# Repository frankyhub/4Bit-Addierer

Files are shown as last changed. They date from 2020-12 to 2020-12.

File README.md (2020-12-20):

# 4Bit-Addierer
Projekt Gymnasium Tegernsee

## [Link zur Dokumentation PDF](https://github.com/frankyhub/4Bit-Addierer/blob/main/doc/4-Bit-Addierer-Dokumentation.pdf)

## Frontplatte


## PCB


## Schaltplan Volladdierer



## Schaltplan vier Volladdierer


## 4Bit-Addierer im Gehäuse




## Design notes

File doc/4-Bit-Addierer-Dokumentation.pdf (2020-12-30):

### 4-Bit-Addierer

### Dokumentation

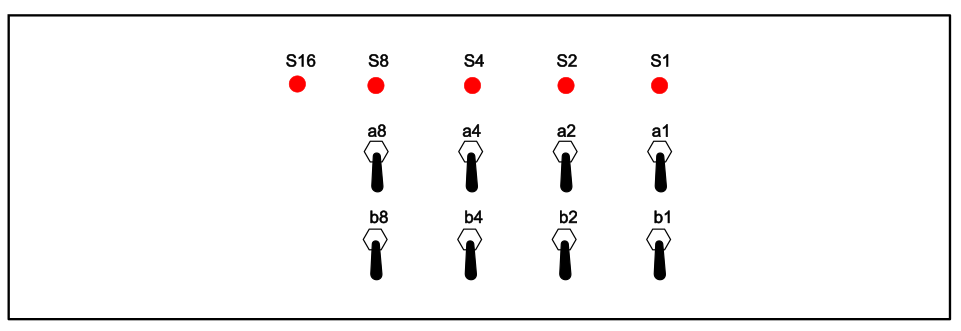
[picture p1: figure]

4-Bit-Addierer

Erstellt: | KHF | Version: | V1.0 | Seite 2 von 6

D:\gittemp\4Bit-Addierer\4-Bit-Addierer-Dokumentation.docx

Beschreibung

Der 4-Bit-Addierer addiert die Bits a1-a8 mit b1-b8 und zeigt die Summe im dualen Zahlensystem mit den LEDs S1-S16 an. Die Beschriftung der Schalter und LEDs resultiert aus der Wertigkeit der Schalter und der LEDs.

Schalter | Wertigkeit binär | Wertigkeit dezimal
a1 | 2 0 | 1
a2 | 2 1 | 2
a4 | 2 2 | 4
a8 | 2 3 | 8
Schalter | Wertigkeit binär | Wertigkeit dezimal
b1 | 0 2 | 1
b2 | 2 1 | 2
b4 | 2 2 | 4
b8 | 3 2 | 8
LED Summe | Wertigkeit binär | Wertigkeit dezimal
S1 | 2 0 | 1
S2 | 2 1 | 2
S4 | 2 2 | 4
S8 | 2 3 | 8
S16 | 4 2 | 16

Schalterstellung unten = 0, Schalterstellung oben = 1

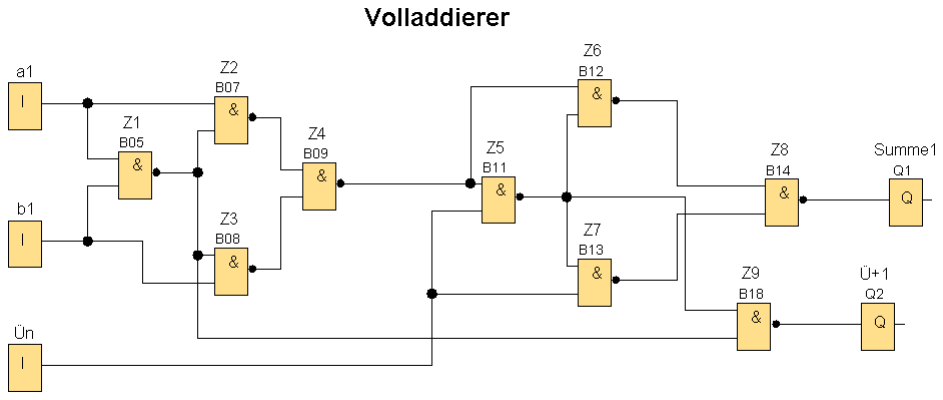
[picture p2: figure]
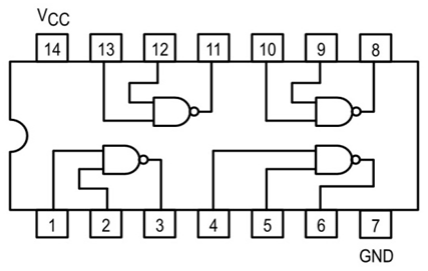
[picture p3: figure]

Erstellt: | KHF | Version: | V1.0 | Seite 3 von 6

Der 4-Bitt-Addierer besteht aus vier Volladdierer:

Ün | a | b | Summe | Ün+1
0 | 0 | 0 | 0 | 0
0 | 0 | 1 | 1 | 0
0 | 1 | 0 | 1 | 0
0 | 1 | 1 | 0 | 1
1 | 0 | 0 | 1 | 0
1 | 0 | 1 | 0 | 1
1 | 1 | 0 | 0 | 1
1 | 1 | 1 | 1 | 1
Funktionstabelle eines Volladdierers

Der 4-Bit-Addierer wurde mit zehn TTL (Transistor-Transistor-Logik) ICs SN74LS00N aufgebaut:

Datasheet SN74LS00N - 4 NAND-Gatter

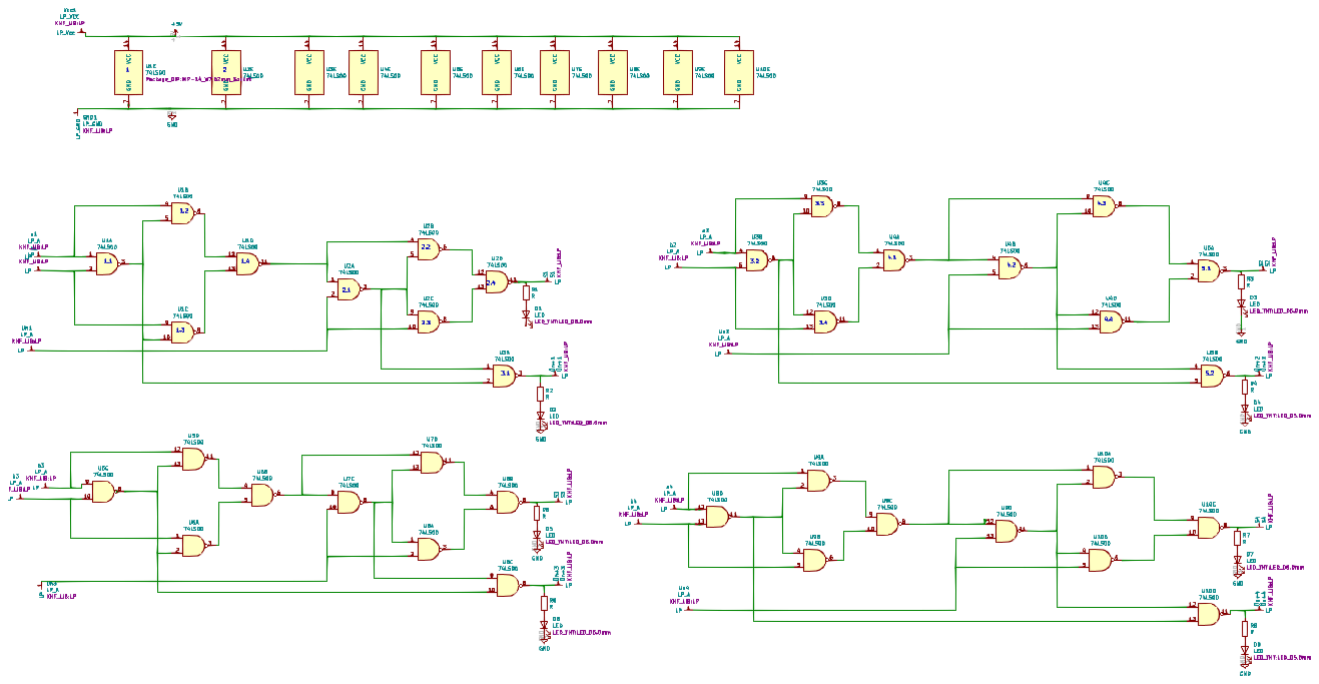
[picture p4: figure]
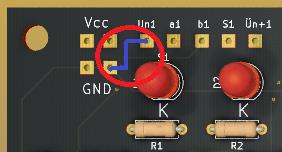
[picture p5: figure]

Erstellt: | KHF | Version: | V1.0 | Seite 4 von 6
Eingang 1 | Eingang 2 | Ausgang
0 | 0 | 1
0 | 1 | 1
0 | 0 | 1
1 | 1 | 0
Funktionstabelle NAND SN74LS00N

Damit die Bits a1-a8 mit den Bits b1-b8 addiert werden können, benötigt man vier Volladdierer.

Schaltplan des 4-Bit-Addierers

Bestehend aus vier Volladdierer

Hinweis: TTL-Bausteine haben die Eigenschaft, einen offenen Eingang als logisch 1 zu erkennen. Deshalb muss der Übertrag Un1 des ersten Addierers mit logisch 0 beschalten werden. Dies erfolgte auf der Platine mit einer Drahtbrücke.

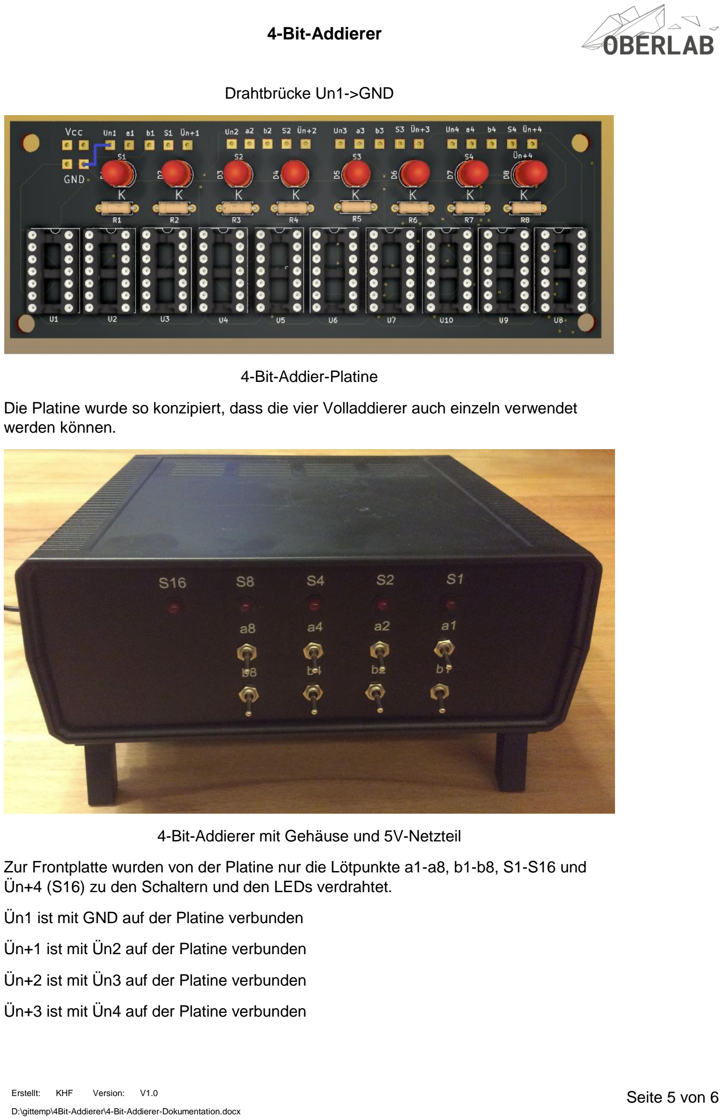
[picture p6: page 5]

Erstellt: | KHF | Version: | V1.0 | Seite 5 von 6

Drahtbrücke Un1->GND

4-Bit-Addier-Platine

Die Platine wurde so konzipiert, dass die vier Volladdierer auch einzeln verwendet werden können.

4-Bit-Addierer mit Gehäuse und 5V-Netzteil

Zur Frontplatte wurden von der Platine nur die Lötpunkte a1-a8, b1-b8, S1-S16 und Ün+4 (S16) zu den Schaltern und den LEDs verdrahtet.

Ün1 ist mit GND auf der Platine verbunden

Ün+1 ist mit Ün2 auf der Platine verbunden

Ün+2 ist mit Ün3 auf der Platine verbunden

Ün+3 ist mit Ün4 auf der Platine verbunden

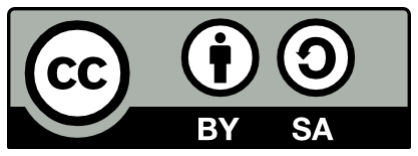
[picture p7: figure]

Erstellt: | KHF | Version: | V1.0 | Seite 6 von 6

Das 5V-Steckenetzteil ist direkt mit der Platine Vcc und GND verbunden. Der Anschluss des Steckernetzteils ist mit einer PNG-Verschraubung und einer Zugentlastung nach außen geführt.

Die Platine ist mit dem Open Source Programm KiCad erstellt worden.

Link: https://kicad.org/download/

Die Frontplatte wurde mit dem Open Source Programm Inkscape erstellt.

Link: https://inkscape.org/de/release/inkscape-1.0.1/

Der Link für den download der Dateien: https://github.com/frankyhub/4Bit-Addierer

Der 4-Bitt-Addierer wurde erstell im

FabLab Oberland e.V.

Tölzer Str. 3A,

83703 Gmund am Tegernsee

Lizenz:

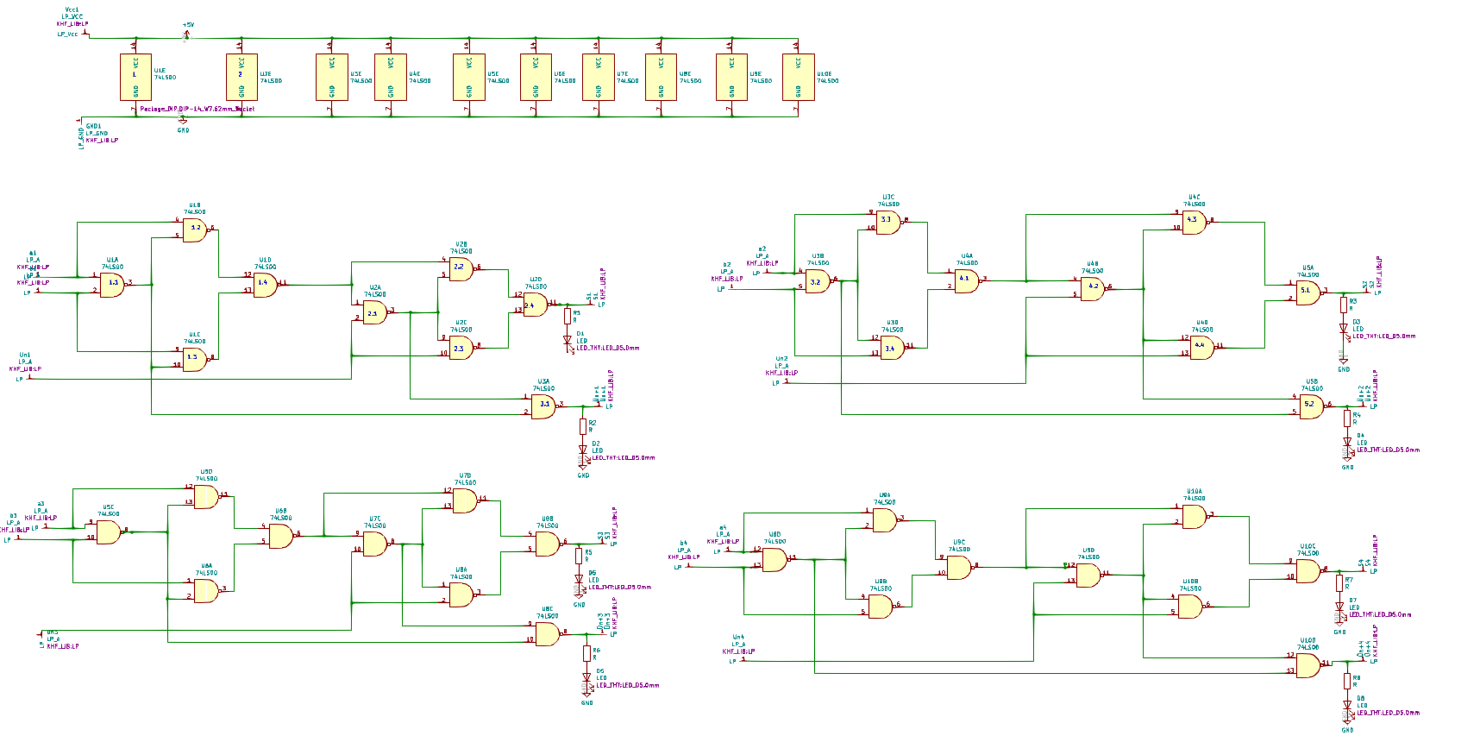
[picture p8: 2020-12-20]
doc/Schaltplan 4-Bit-Addierer.png

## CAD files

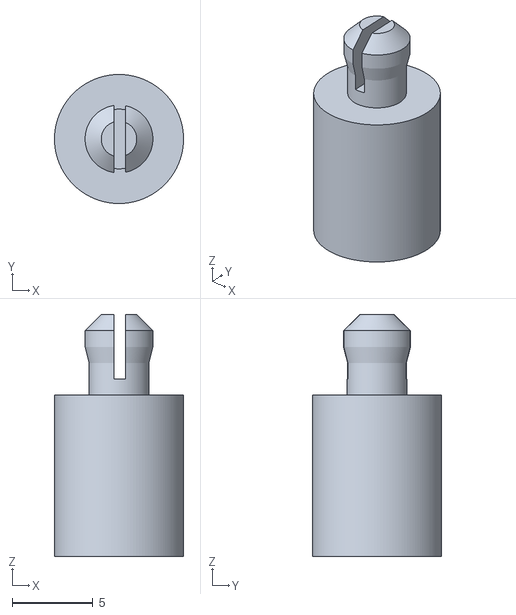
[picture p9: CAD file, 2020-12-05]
Slicer/PIN_4mm.stl
8.00 x 8.00 x 15.0

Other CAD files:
Slicer/PIN_4mm.scad

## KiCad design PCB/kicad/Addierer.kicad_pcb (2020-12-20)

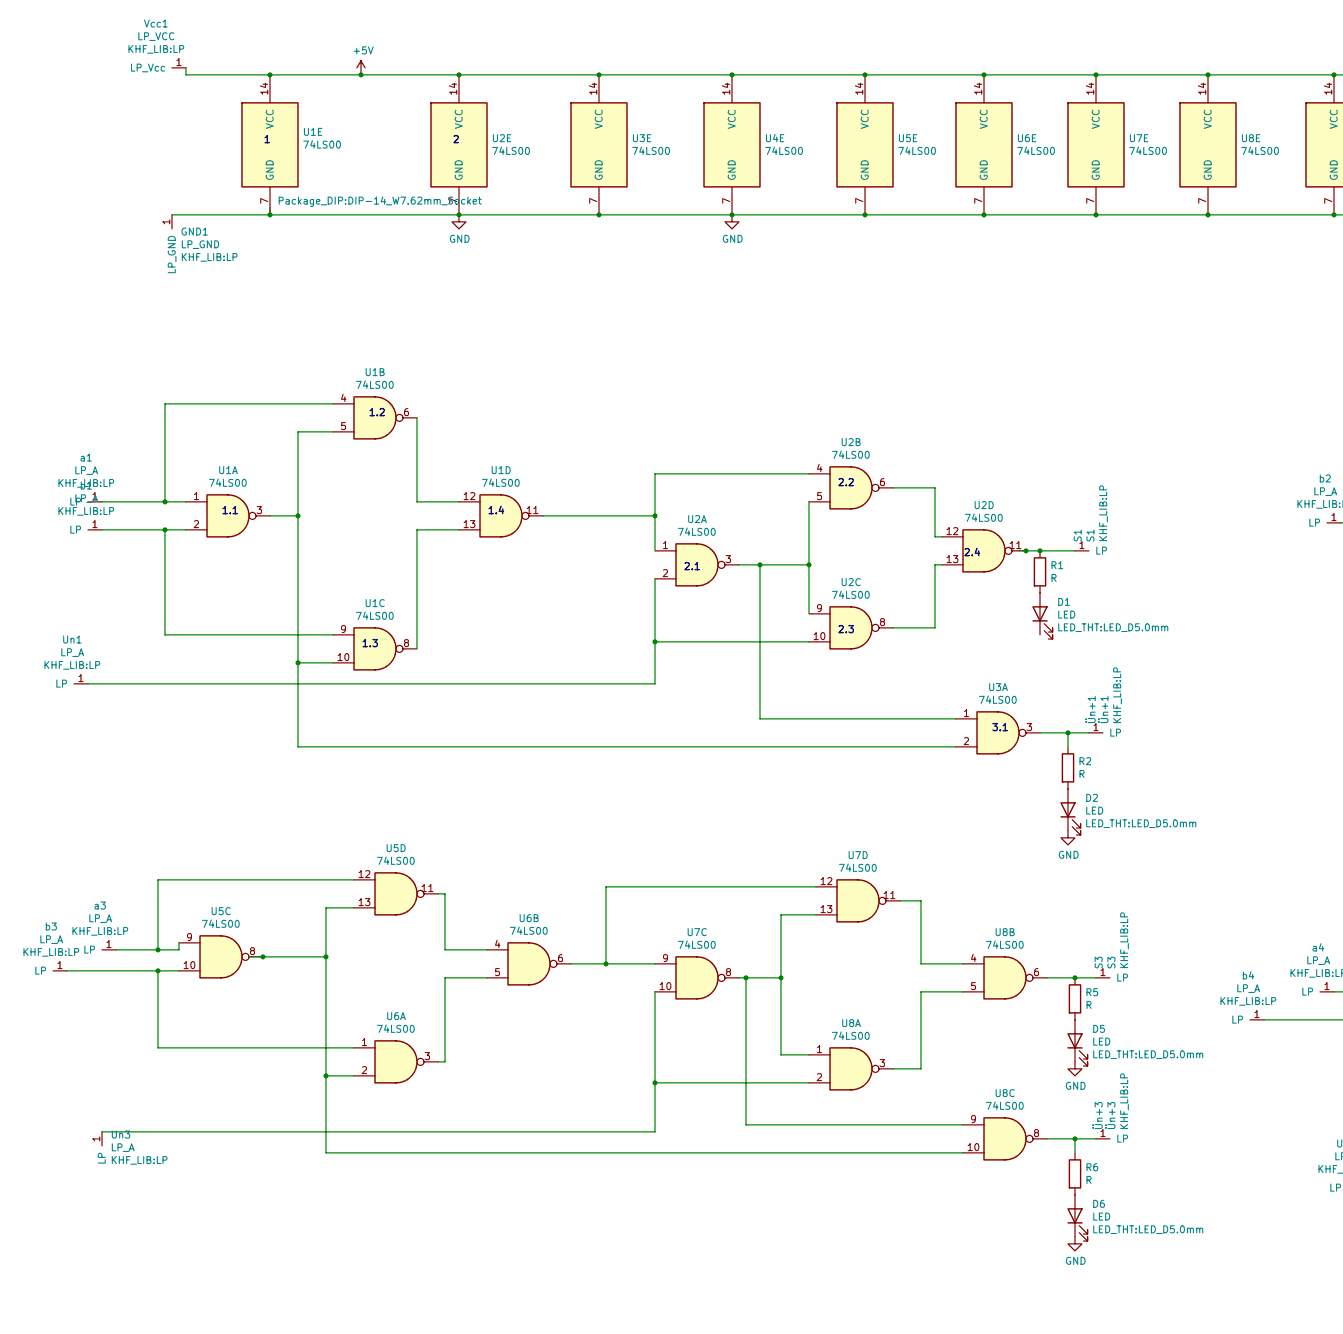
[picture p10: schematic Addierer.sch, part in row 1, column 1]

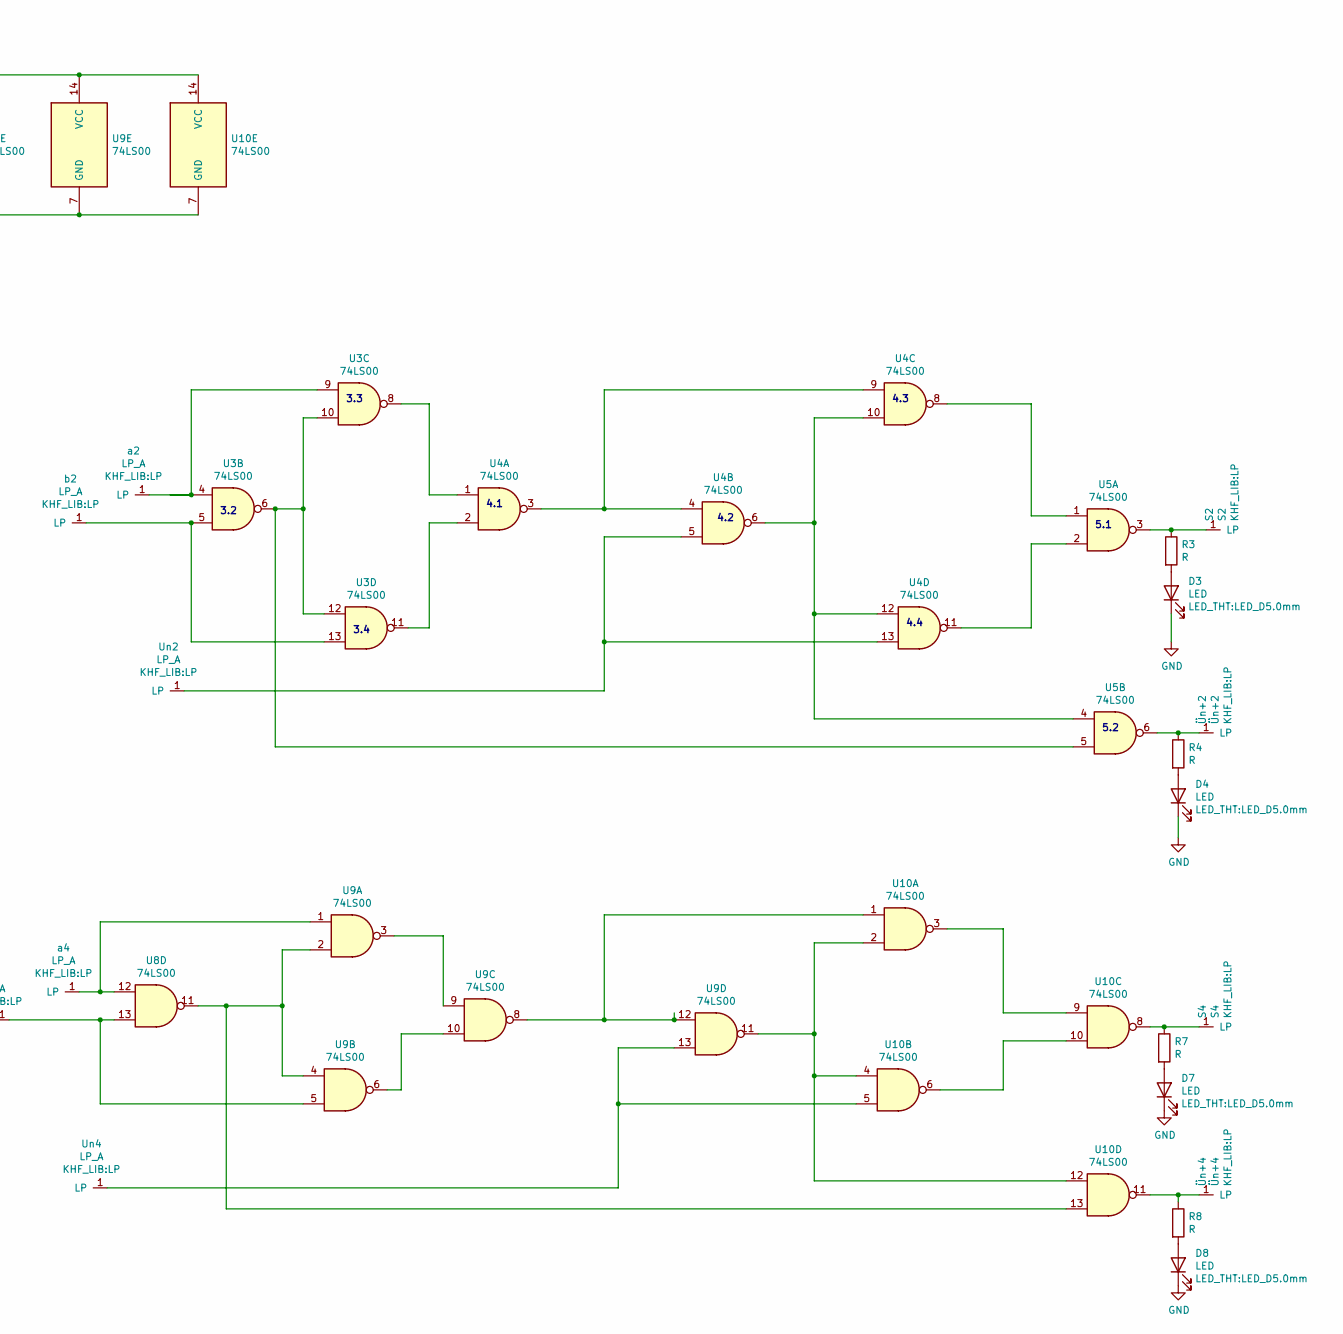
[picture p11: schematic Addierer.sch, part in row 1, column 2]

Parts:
D1, D2, D3, D4, D5, D6, D7, D8: LED; LED_D5.0mm
GND1: LP_GND; LP
R1, R2, R3, R4, R5, R6, R7, R8: R; R_Axial_DIN0207_L6.3mm_D2.5mm_P7.62mm_Horizontal
S1: S1; LP
S2: S2; LP
S3: S3; LP
S4: S4; LP
U1, U2, U3, U4, U5, U6, U7, U8, U9, U10: 74LS00; DIP-14_W7.62mm_Socket
Un1, Un2, Un3, Un4: LP_A; LP
Vcc1: LP_VCC; LP
a1, a2, a3, a4: LP_A; LP
b1, b2, b3, b4: LP_A; LP
Ün+1: Ün+1; LP
Ün+2: Ün+2; LP
Ün+3: Ün+3; LP
Ün+4: Ün+4; LP

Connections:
+5V: U1.14 (VCC), U2.14 (VCC), U3.14 (VCC), U4.14 (VCC), U5.14 (VCC), U6.14 (VCC), U7.14 (VCC), U8.14 (VCC), U9.14 (VCC), U10.14 (VCC), Vcc1.1; also elsewhere on the board
GND: D1.1 (K), D2.1 (K), D3.1 (K), D4.1 (K), D5.1 (K), D6.1 (K), D7.1 (K), D8.1 (K), GND1.1, U1.7 (GND), U2.7 (GND), U3.7 (GND), U4.7 (GND), U5.7 (GND), U6.7 (GND), U7.7 (GND), U8.7 (GND), U9.7 (GND), U10.7 (GND); also elsewhere on the board
unnamed: D1.2 (A), R1.2
unnamed: D2.2 (A), R2.2
unnamed: D3.2 (A), R3.2
unnamed: D4.2 (A), R4.2
unnamed: D5.2 (A), R5.2
unnamed: D6.2 (A), R6.2
unnamed: D7.2 (A), R7.2
unnamed: D8.2 (A), R8.2
unnamed: R1.1, S1.1, U2.11
unnamed: R2.1, U3.3, Ün+1.1
unnamed: R3.1, S2.1, U5.3
unnamed: R4.1, U5.6, Ün+2.1
unnamed: R5.1, S3.1, U8.6
unnamed: R6.1, U8.8, Ün+3.1
unnamed: R7.1, S4.1, U10.8
unnamed: R8.1, U10.11, Ün+4.1
unnamed: U1.1, U1.4, a1.1
unnamed: U1.2, U1.9, b1.1
unnamed: U1.3, U1.5, U1.10, U3.2
unnamed: U1.11, U2.1, U2.4
unnamed: U1.6, U1.12
unnamed: U1.8, U1.13
unnamed: U2.3, U2.5, U2.9, U3.1
unnamed: U2.2, U2.10, Un1.1
unnamed: U2.6, U2.12
unnamed: U2.8, U2.13
unnamed: U3.4, U3.9, a2.1
unnamed: U3.8, U4.1
unnamed: U3.6, U3.10, U3.12, U5.5
unnamed: U3.11, U4.2
unnamed: U3.5, U3.13, b2.1
unnamed: U4.3, U4.4, U4.9
unnamed: U4.8, U5.1
unnamed: U4.6, U4.10, U4.12, U5.4
unnamed: U4.11, U5.2
unnamed: U4.5, U4.13, Un2.1
unnamed: U5.10, U6.1, b3.1
unnamed: U5.11, U6.4
unnamed: U5.9, U5.12, a3.1
unnamed: U5.8, U5.13, U6.2, U8.10
unnamed: U6.3, U6.5
unnamed: U6.6, U7.9, U7.12
unnamed: U7.10, U8.2, Un3.1
unnamed: U7.11, U8.4
unnamed: U7.8, U7.13, U8.1, U8.9
unnamed: U8.3, U8.5
unnamed: U8.12, U9.1, a4.1
unnamed: U8.13, U9.5, b4.1
unnamed: U9.3, U9.9
unnamed: U9.6, U9.10
unnamed: U9.8, U9.12, U10.1
unnamed: U10.3, U10.9
unnamed: U9.13, U10.5, Un4.1
unnamed: U10.6, U10.10
unnamed: U9.11, U10.2, U10.4, U10.12
unnamed: U8.11, U9.2, U9.4, U10.13

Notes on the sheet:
1.1
1.2
1.3
1.4
2.1
2.2
2.3
2.4
3.1
3.2
3.3
3.4
4.1
4.2
4.3
4.4
5.1
5.2

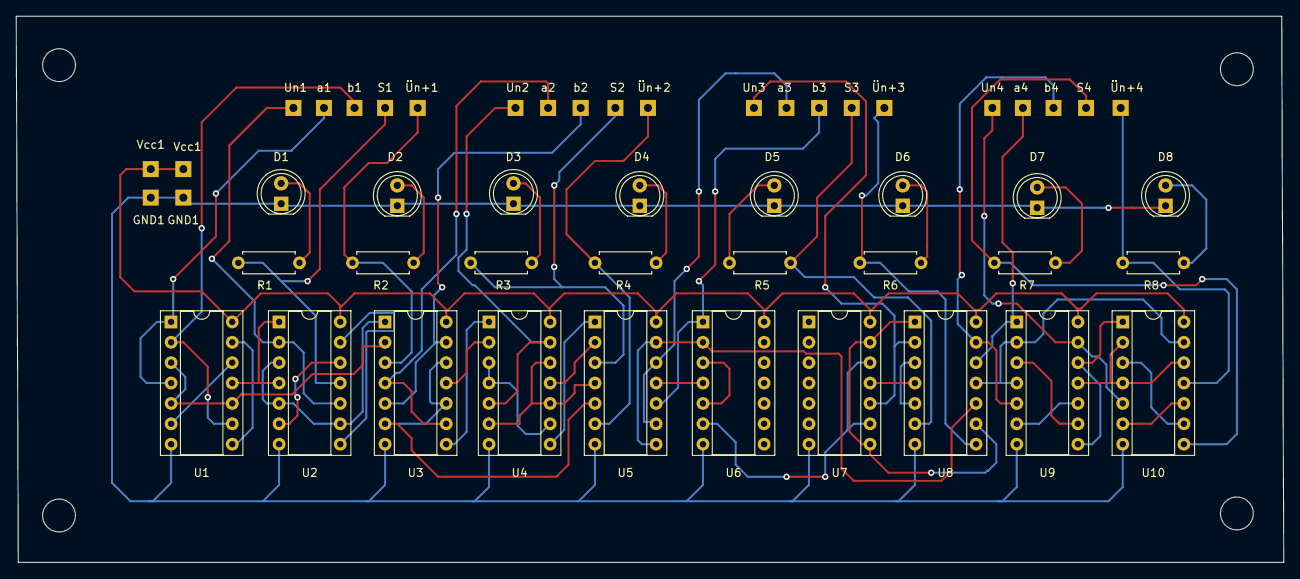
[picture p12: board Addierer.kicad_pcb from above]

Board: 2 copper layers, 158.0 x 68.1 mm, 50 parts (0 on the bottom side), 58 nets.

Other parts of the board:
GND1#2: LP_GND; LP
Vcc1#2: LP_VCC; LP

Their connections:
+5V: Vcc1#2.1; also elsewhere on the board
GND: GND1#2.1; also elsewhere on the board
